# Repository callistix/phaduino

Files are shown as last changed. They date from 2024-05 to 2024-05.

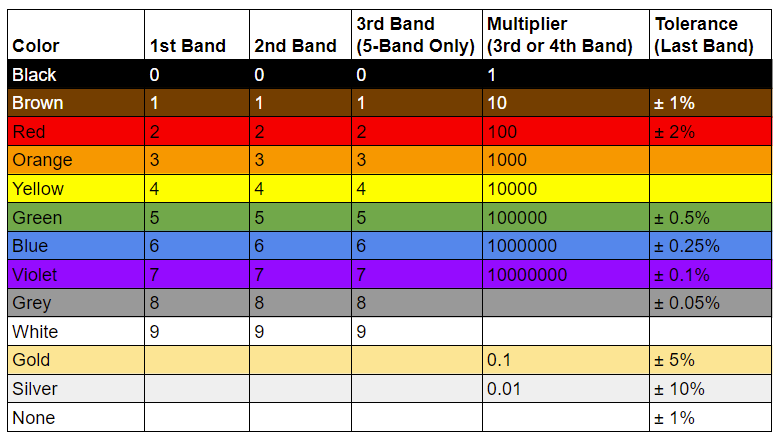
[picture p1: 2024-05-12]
reference/resistor_color_code.png

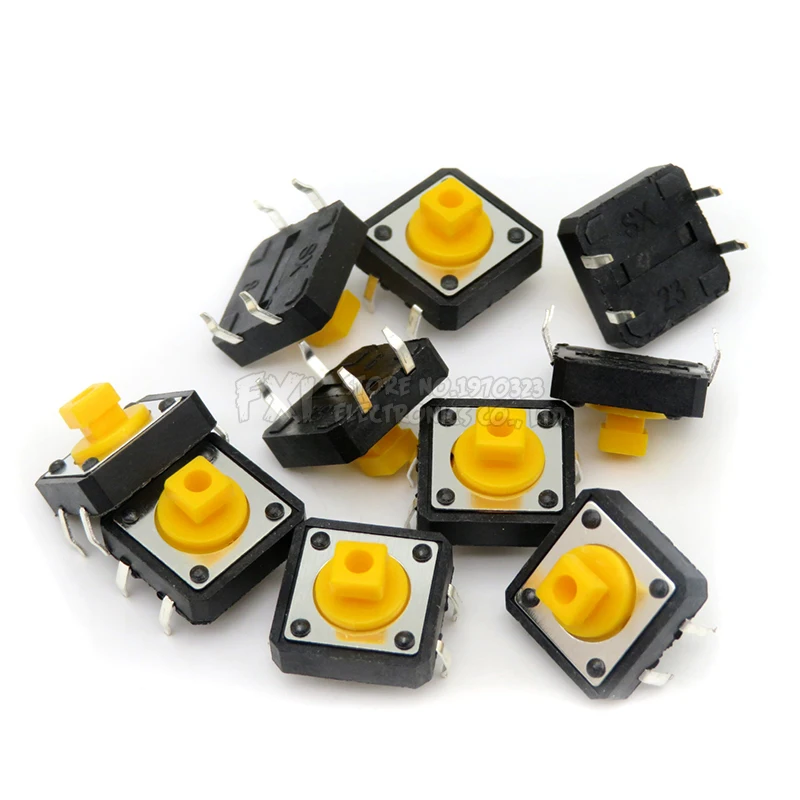
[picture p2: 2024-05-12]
datasheets/Mini Push Button 2.png

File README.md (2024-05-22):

# Requirements

* `apt-get install arduino`
* in Arduino IDE install following libraries:
** MIDI Library
** `CD74HC4067`

# Usage

* flash the original firmware for uploading sketches:

```bash
cd sh
./flash_usbserial
```

* flash the midi firmware to make it appear as MIDI device:

```bash
cd sh
./flash_midi
```

# Print settings

* filament:
    * SUNLU PLA+ black (main)
    * SUNLU PLA+ white (labels)

* nozzle temp.: 220 degrees
* build plate temp.: 75 degrees
* wall line count: 3
* top / bottom layers: 3
* infill: gyroid 20%
* print speed: 50mm/s
* infill speed: 75mm/s
* support speed: 75mm/s
* travel speed: 200mm/s
* retraction distance: 8.0mm
* fan speed: 100%
* support pattern: Zig Zag
* support density: 10%
* use adaptive layers: no

* "Pause at height" setting for filament changing:
    * pause layer: last layer before labels
    * method: BQ
    * keep motors engaged
    * park print: yes
    * retraction: 450mm
    * standby temperature: 220 deg.
    * beep at pause
* enable draft shield: yes (to prime extruder after filament change)

# Notes

* let hot bed cool down entirely before attempting to remove print, or otherwise it will warp

# To-do

* build plate needs leveling, right side seems more faint
* when changing to white filament layers, increase nozzle temperature and retraction distance to i.e. 9 or 10mm
    * for black filament, lower to i.e. 6 or 7 mm retraction distance and 220 degrees
* make pot labels font size 1 pixel bigger for better readability
* test and define the way the pieces attach to each other
    * maybe remove screws 5 and 6 again, then print intermediate connector parts

# Links

## Arduino basics

* [Arduino Push Button Tutorial (step by step)](https://www.youtube.com/watch?v=J_07uwur_MI&t=32s)
* [Arduino LED – Complete Tutorial](https://roboticsbackend.com/arduino-led-complete-tutorial/)

## Arduino MIDI controller

* [Quick Hack! - USB MIDI Controller with Arduino UNO](https://www.youtube.com/watch?v=3haK5QGbi_E)
* [Arduino MIDI Library Documentation](https://fortyseveneffects.github.io/arduino_midi_library/index.html)

## Multiplexing analogue pins

* [How can I connect multiple potentiometers (~20) to my Arduino without having to have 20 analogue pins?](https://electronics.stackexchange.com/questions/659309/how-can-i-connect-multiple-potentiometers-20-to-my-arduino-without-having-to)
* [Arduino CD74HC4067 Analog Multiplexer Library, Code Example](https://deepbluembedded.com/arduino-cd74hc4067-analog-multiplexer-library-code/)
* [Muxing Around With The CD74HC4067 + Arduino](https://adam-meyer.com/arduino/CD74HC4067)

## Multiplexing LEDs

* [Multiplexing 7 Segment Displays With Arduino and Shift Registers](https://www.instructables.com/Multiplexing-7-Segment-displays-with-Arduino-and-S/)
* [Charlieplexing](https://en.wikipedia.org/wiki/Charlieplexing)
* [Multiplexing With Arduino and the 74HC595](https://www.instructables.com/Multiplexing-with-Arduino-and-the-74HC595/)
* [Controlling LEDs with A Multiplexer and Arduino](https://makersportal.com/blog/2019/3/12/controlling-leds-with-multiplexer-and-arduino)

## `TLC5947`

* [TLC5947 and TLC59711 PWM LED Driver Breakouts](https://learn.adafruit.com/tlc5947-tlc59711-pwm-led-driver-breakout/overview)
* [Interfacing TLC5947 PWM Module with Arduino (12-Bit LED Drivers)](https://electropeak.com/learn/interfacing-tlc5947-pwm-module-with-arduino-12-bit-led-drivers/)

## 3D Print labelling

* [Labeling Your Parts with Engraver Filler](https://markforged.com/resources/blog/engraver-filler-labeling)
* [3D Print Inlay Lettering](https://www.youtube.com/watch?v=W2f5lI1R6dg)
* [Finishing 3D prints with nailpolish and acetone](https://www.youtube.com/watch?v=4iX6x2MLhH0)

## FreeCAD

* [Draft ShapeString](https://wiki.freecad.org/Draft_ShapeString)
* [Draft ShapeString tutorial](https://wiki.freecad.org/Draft_ShapeString_tutorial)
* [How to create solids from 2D image?](https://www.xsim.info/articles/FreeCAD/en-US/HowTo/Create-solids-from-2D-image.html)

## Measuring

* [How to Measure Amperage](https://www.wikihow.com/Measure-Amperage)

## C++
* [ArduinoSTL](https://github.com/mike-matera/ArduinoSTL)

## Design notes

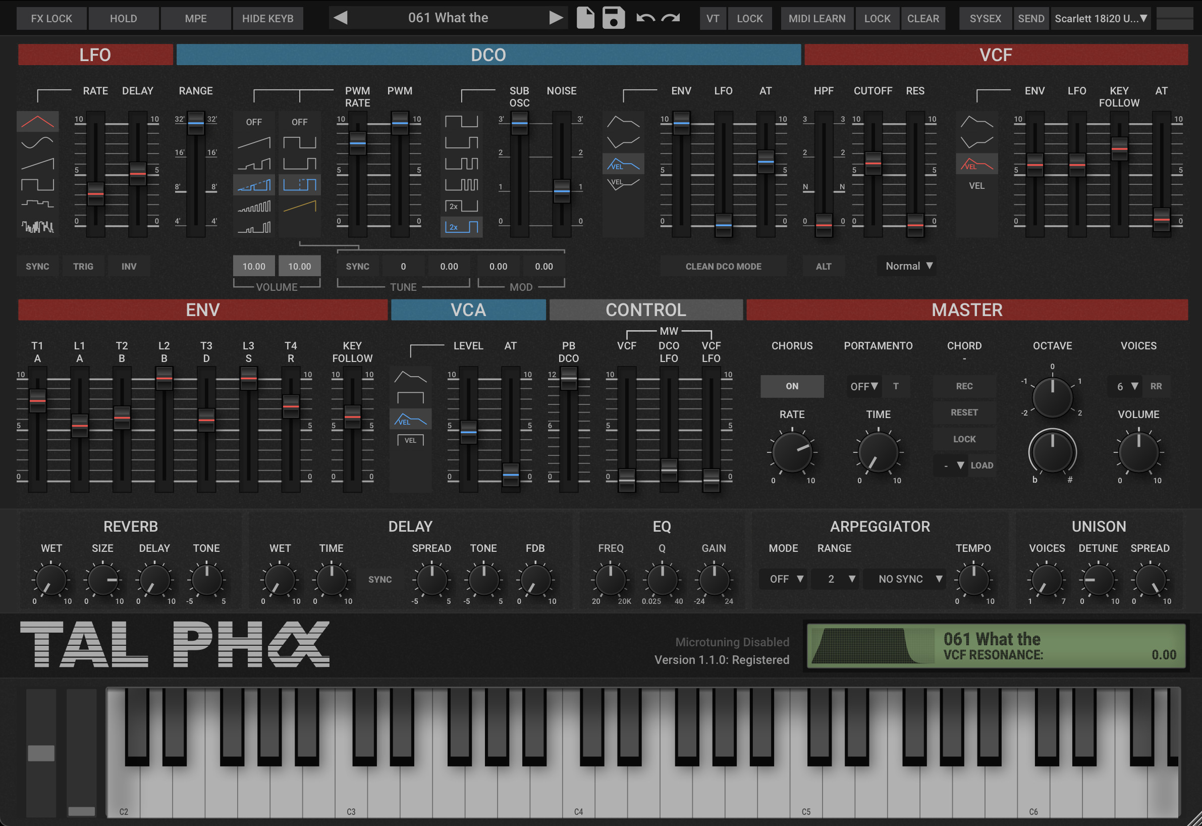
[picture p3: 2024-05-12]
reference/tal-pha.jpg

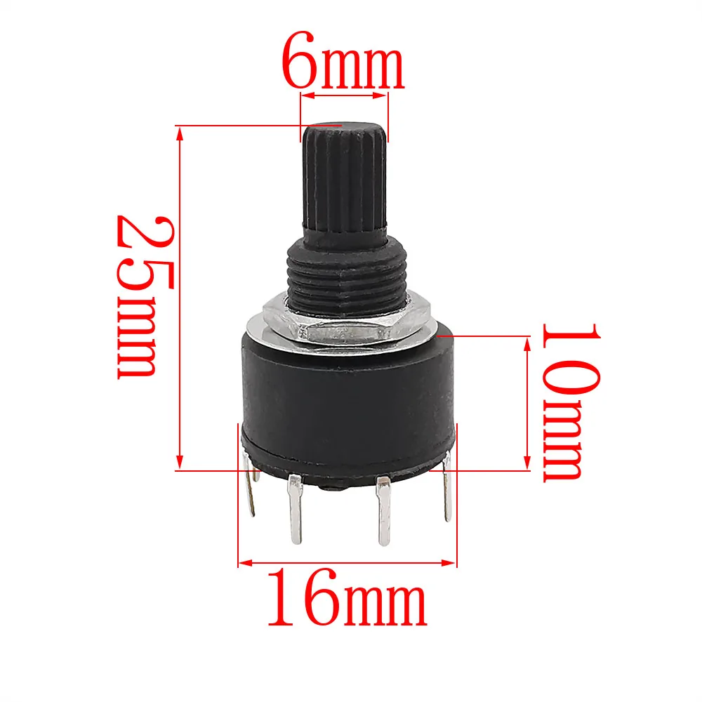
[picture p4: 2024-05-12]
datasheets/SR16 16mm Rotary Band Switch 1 Pole 5 Positions 1.png

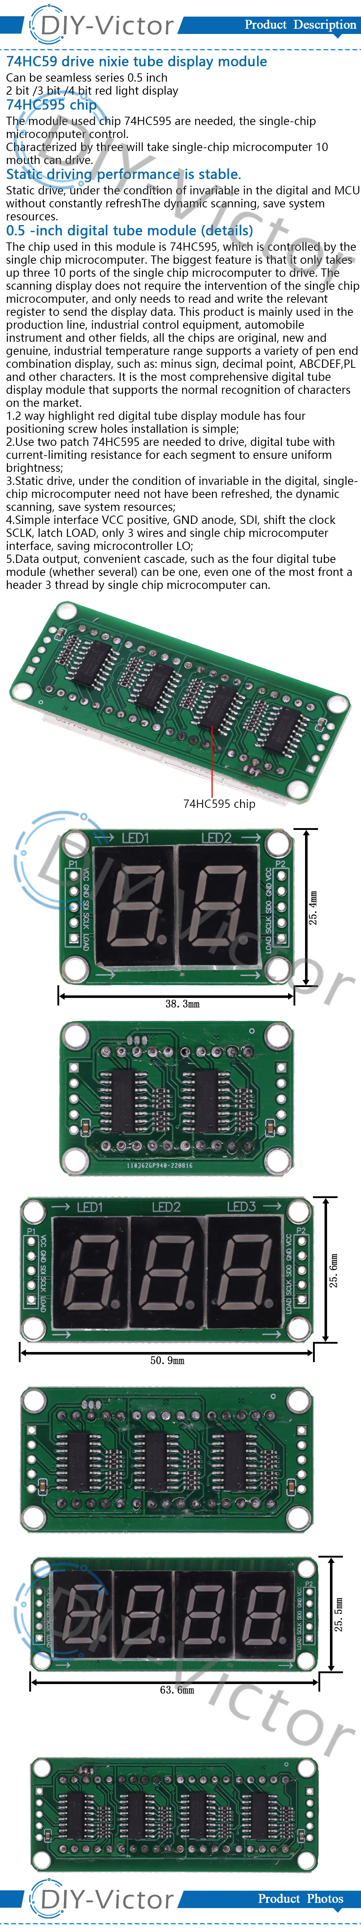
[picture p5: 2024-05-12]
datasheets/5011BS LED 7-Segment Display & SN74HC595.png

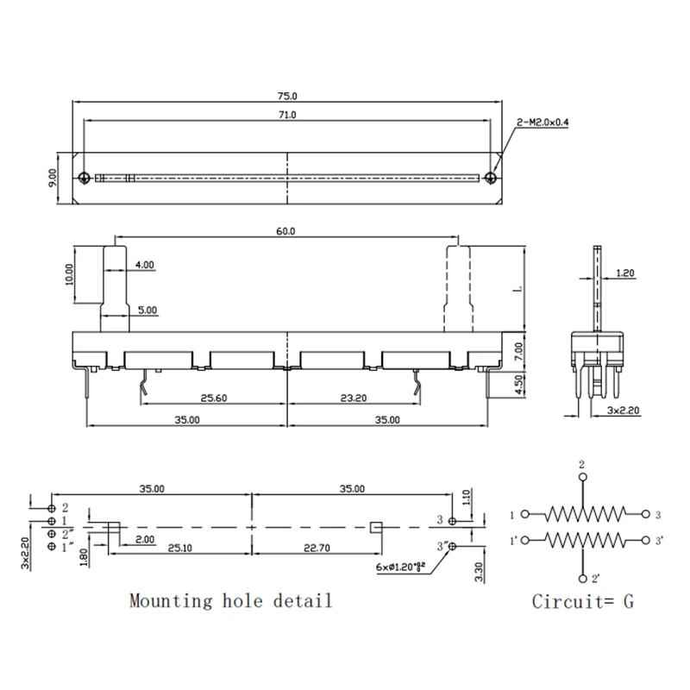
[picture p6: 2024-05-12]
datasheets/SC6080GH 75mm Slide Potentiometer 10k.png

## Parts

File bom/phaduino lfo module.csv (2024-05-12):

Reference | Value | Datasheet | Footprint | Qty | DNP
A1 | Arduino_UNO_R3 | https://www.arduino.cc/en/Main/arduinoBoardUno | Module:Arduino_UNO_R3 | 1
D1/D2/D3 | LED | ~ |  | 3
R1 | 1k | ~ |  | 1
R2 | 560R | ~ |  | 1
R3 | 460R | ~ |  | 1
R4/R7 | 390R | ~ |  | 2
R5/R8 | 180R | ~ |  | 2
R6/R9 | 56R | ~ |  | 2
R10/R11 | 220R | ~ |  | 2
RV1/RV2 | SC6080GH R_Potentiometer | https://ae01.alicdn.com/kf/S4e5feccce45d4e90a10ab3d2473ecfbaM.jpg |  | 2
SW1 | SR16 SW_Rotary_1x6_MP | https://ae01.alicdn.com/kf/S429ed770be804cc08330cb0ba17e1a0cW.jpg |  | 1
SW2/SW3/SW4 | SW_Push | https://ae01.alicdn.com/kf/Ha64b855cd2af4a9e8355bdf6917cb93dQ.jpg |  | 3
U1 | CD74HC4067M | http://www.ti.com/lit/ds/symlink/cd74hc4067.pdf | Package_SO:SOIC-24W_7.5x15.4mm_P1.27mm | 1
U2 | TLC5947DAP | https://www.ti.com/lit/ds/symlink/tlc5947.pdf | Package_SO:HTSSOP-32-1EP_6.1x11mm_P0.65mm_EP5.2x11mm_Mask4.11x4.36mm_ThermalVias | 1

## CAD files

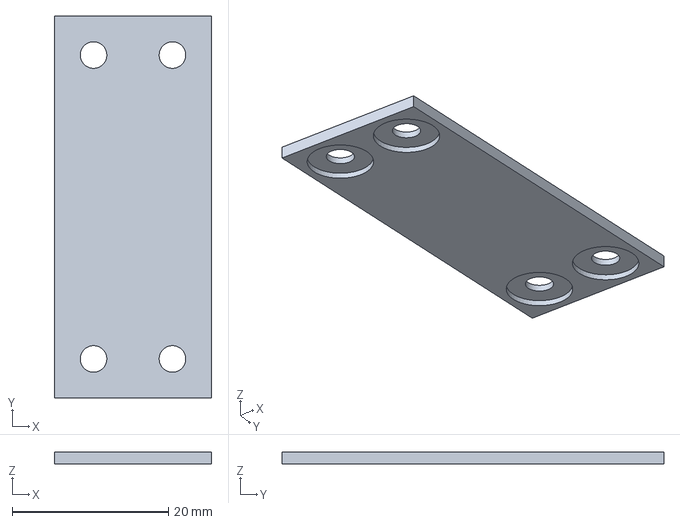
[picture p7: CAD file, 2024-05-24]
freecad/frame.FCStd
20.1 x 48.9 x 1.50 mm

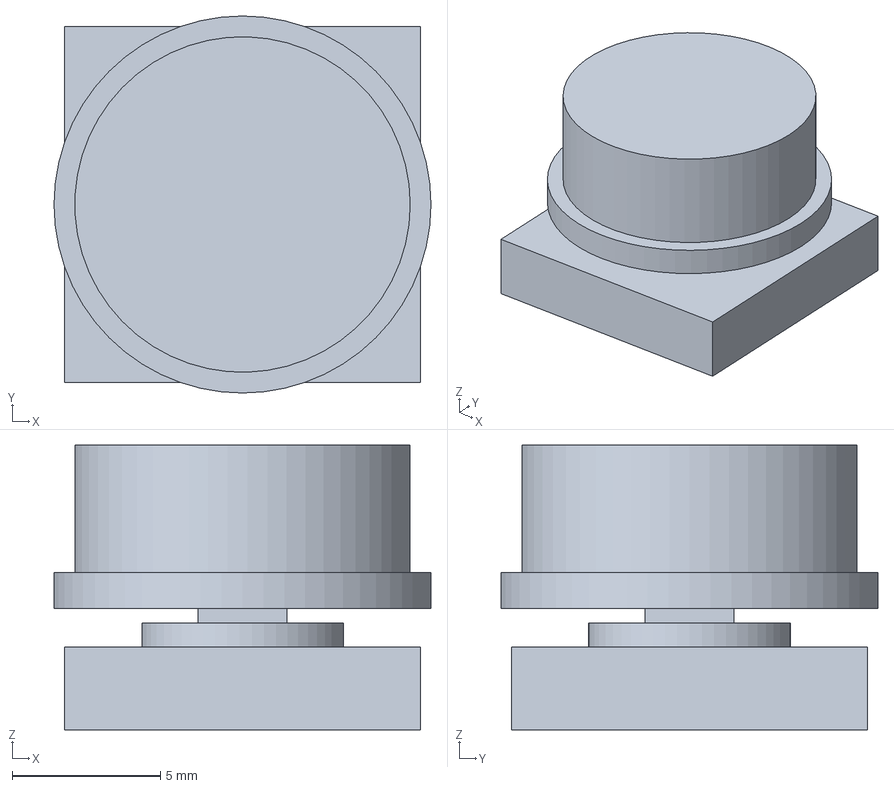
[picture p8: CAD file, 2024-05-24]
freecad/parts/mini_push_button.FCStd
12.7 x 12.7 x 9.60 mm

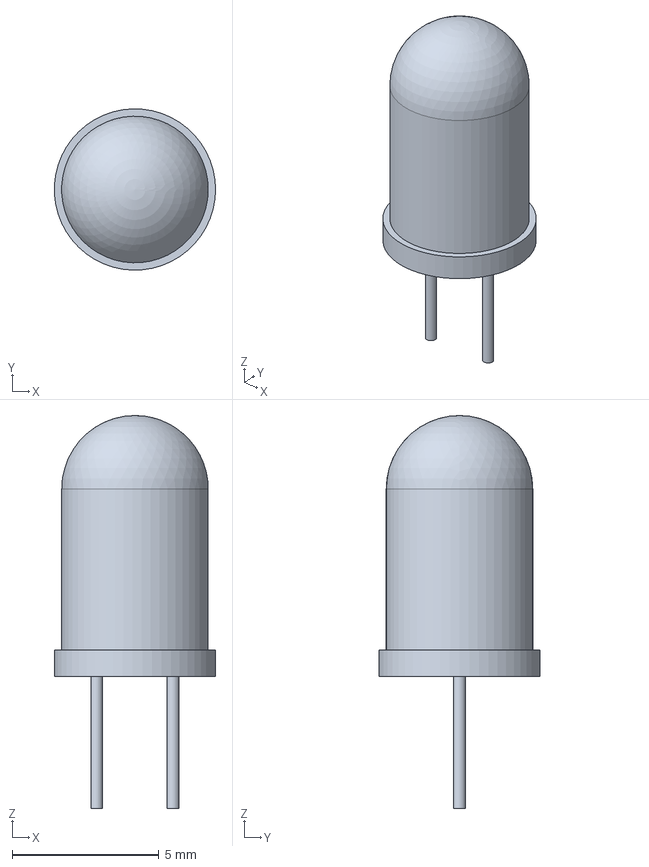
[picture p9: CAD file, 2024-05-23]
freecad/parts/led.FCStd
5.49 x 5.50 x 13.4 mm

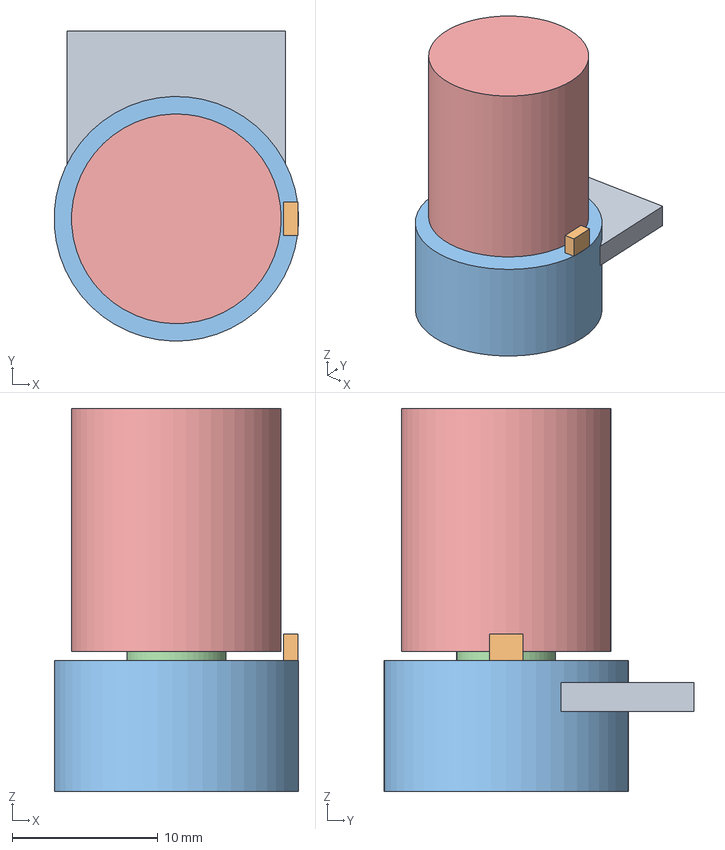
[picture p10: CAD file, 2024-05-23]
freecad/parts/pot_r.FCStd
16.8 x 21.3 x 26.3 mm
pot_connectors
pot_notch
pot_body
pot_shaft
pot_knob
pot_washer

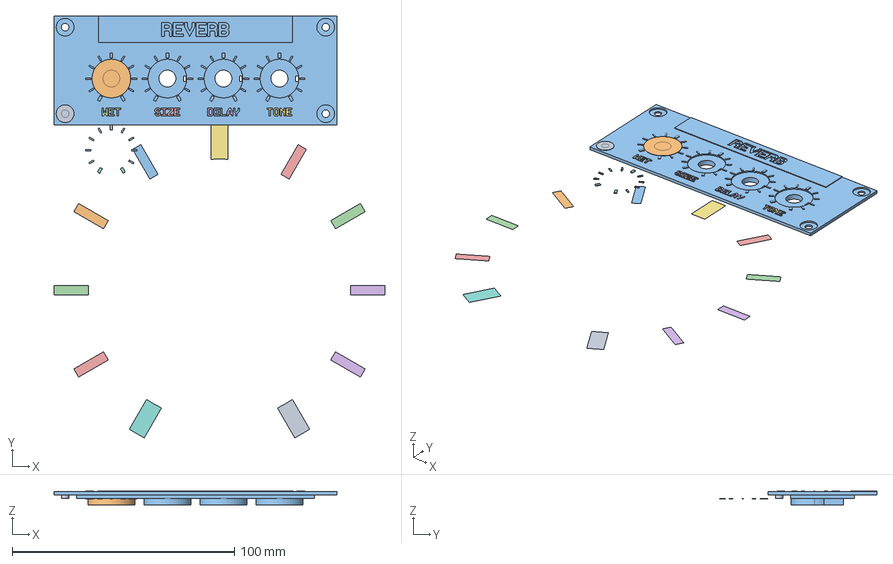
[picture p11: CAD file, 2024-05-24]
freecad/reverb.FCStd
148.8 x 189.7 x 6.32 mm
panel_slit_1
pot_cage_1
title
label_1
label_2
label_3
label_4
label_dial_1
panel_screw_1
panel_pot_cut_1
panel
rect2637
rect2637_008
rect2637_009
rect2637_3
rect2637_3_2
rect2637_3_6
rect2637_6
rect2637_6_5
rect2637_7
rect2637_7_5
rect2638

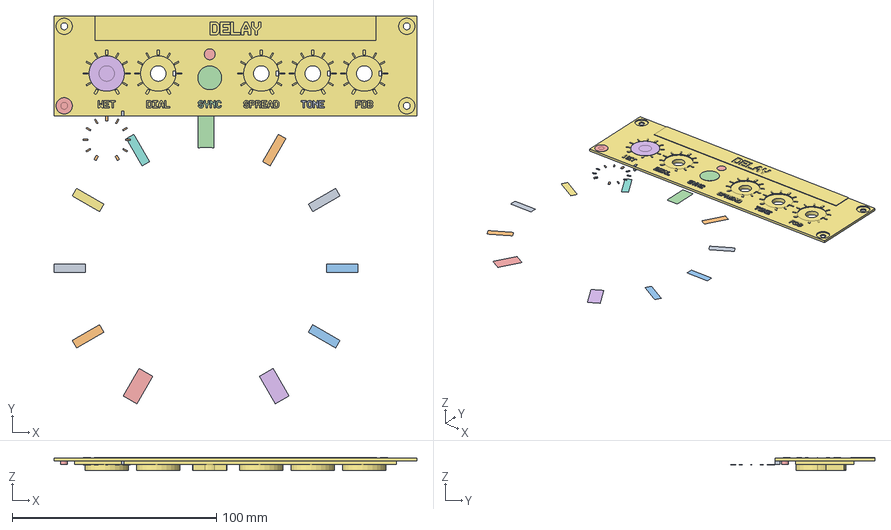
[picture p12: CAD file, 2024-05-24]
freecad/delay.FCStd
177.6 x 189.7 x 6.32 mm
panel_slit_1
pot_cage_1
title
push_cut
led_cut
label_1
label_2
label_4
label_5
label_dial_1
label_6
label_3
panel_screw_1
panel_pot_cut_1
panel
push_led_cage
rect2637
rect2637_008
rect2637_009
rect2637_3
rect2637_3_2
rect2637_3_6
rect2637_6
rect2637_6_5
rect2637_7
rect2637_7_5
rect2638

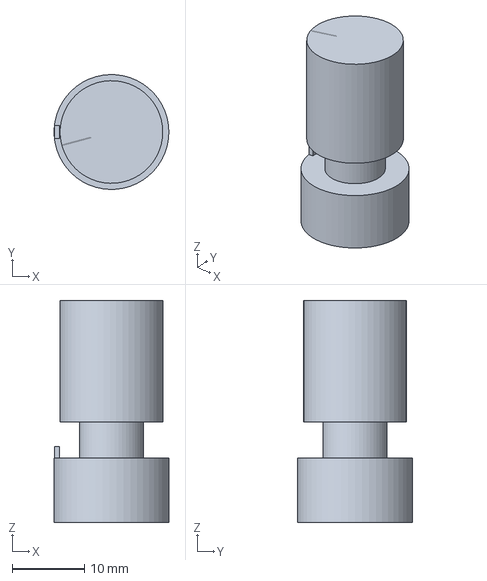
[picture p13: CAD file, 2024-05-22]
freecad/parts/switch_rot.FCStd
15.9 x 15.9 x 30.7 mm

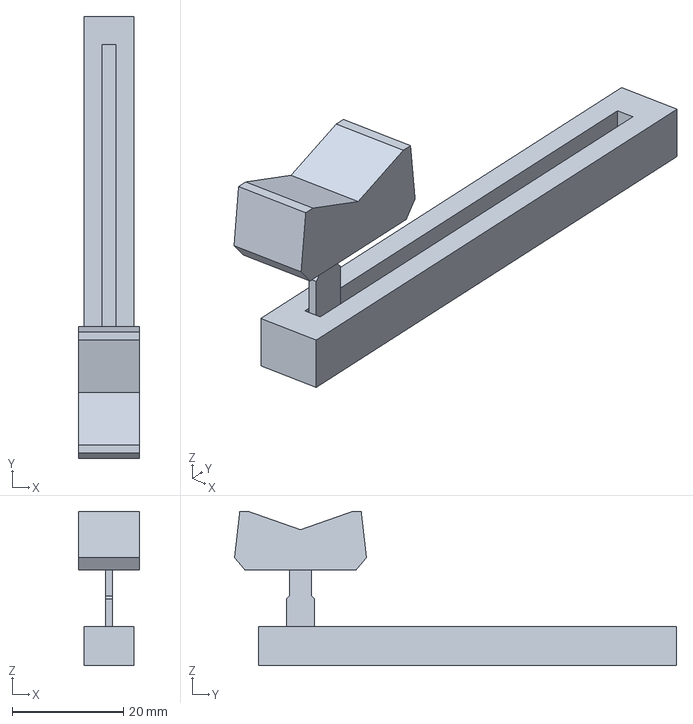
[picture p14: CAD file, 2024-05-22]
freecad/parts/pot_slide.FCStd
10.9 x 79.3 x 27.7 mm

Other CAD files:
freecad/main.FCStd
freecad/parts/pot.FCStd

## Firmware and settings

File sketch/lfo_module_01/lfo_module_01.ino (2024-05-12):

/* TODO:
   * midi_cc are still unstable for potentiometers at certain positions
   * needs optimisation especially for reading LFO buttons
*/

#include "Adafruit_TLC5947.h"


#define BAUD 9600
#define DELAY 1
#define POT_AVG 3
#define MUX_COUNT 1
#define RES_TOLERANCE 5
#define SWITCH_TOLERANCE 10

#define TLC_NUM 1
#define TLC_DATA 6
#define TLC_CLOCK 7
#define TLC_LATCH 8
#define TLC_OE -1


const int mux_signal_pin = A0;

const int mux[MUX_COUNT][4] = {
	{2, 3, 4, 5},
};

const int mux_channel[16][4]={
	{0,0,0,0},
	{1,0,0,0},
	{0,1,0,0},
	{1,1,0,0},
	{0,0,1,0},
	{1,0,1,0},
	{0,1,1,0},
	{1,1,1,0},
	{0,0,0,1},
	{1,0,0,1},
	{0,1,0,1},
	{1,1,0,1},
	{0,0,1,1},
	{1,0,1,1},
	{0,1,1,1},
	{1,1,1,1}
};

const int btn_lfo_sync_res = 369;
const int btn_lfo_trig_res = 562;
const int btn_lfo_sync_trig_res = 654;
const int btn_lfo_inv_res = 811;
const int btn_lfo_sync_inv_res = 832;
const int btn_lfo_trig_inv_res = 865;

const int switch_6_pos_res[] = {802, 557, 365, 325, 286, 182};

typedef struct {
	int val[POT_AVG];
    int val_ptr = 0;
    int midi_cc = 0;
} potentiometer_t;


typedef struct {
    bool sync = false;
    bool sync_hold = false;
    bool trig = false;
    bool trig_hold = false;
    bool inv = false;
    bool inv_hold = false;
} buttons_lfo_t;

typedef struct {
    int midi_cc = 0;
} switch_6_pos_t;


Adafruit_TLC5947 tlc = Adafruit_TLC5947(TLC_NUM, TLC_CLOCK, TLC_DATA, TLC_LATCH);

potentiometer_t pot_lfo_rate;
potentiometer_t pot_lfo_delay;

buttons_lfo_t buttons_lfo;

switch_6_pos_t switch_lfo_wave;


void setup() {
    Serial.begin(BAUD);

    tlc.begin();

    tlc.setLED(0,4059,0,0);
    tlc.write();

	pot_init(pot_lfo_rate);
	pot_init(pot_lfo_delay);

    for (int i = 0; i < MUX_COUNT; i++) {
        mux_init_pins(mux[i]);
	    mux_switch_channel(mux[0], 0);
    }
}


void loop() {
    int midi_cc = 0;

    midi_cc = mux_read_pot(0, 0, pot_lfo_rate);

    if (midi_cc != pot_lfo_rate.midi_cc) {
        pot_lfo_rate.midi_cc = midi_cc;

        Serial.print("LFO RATE: ");
        Serial.println(pot_lfo_rate.midi_cc);
    }

    midi_cc = mux_read_pot(0, 1, pot_lfo_delay);

    if (midi_cc != pot_lfo_delay.midi_cc) {
        pot_lfo_delay.midi_cc = midi_cc;

        Serial.print("LFO DELAY: ");
        Serial.println(pot_lfo_delay.midi_cc);
    }

    mux_read_buttons_lfo(0, 2, buttons_lfo);

    midi_cc = mux_read_6_pos_switch(0, 3, switch_lfo_wave);

    if ((midi_cc != -1) && (midi_cc != switch_lfo_wave.midi_cc)) {
        switch_lfo_wave.midi_cc = midi_cc;

        Serial.print("LFO WAVE: ");
        Serial.println(switch_lfo_wave.midi_cc);
    }

    delay(DELAY);
}


int mux_read_pot(int mux_no, int channel, potentiometer_t &pot) {
    int midi_cc = 0;

    mux_switch_channel(mux_no, channel);

    pot.val[pot.val_ptr] = analogRead(A0);

    pot.val_ptr++;
    if (pot.val_ptr >= POT_AVG) pot.val_ptr = 0;

    midi_cc = val2midi_cc(avg(pot.val, POT_AVG));

    return(midi_cc);
}


void mux_read_buttons_lfo(int mux_no, int channel, buttons_lfo_t &btns) {
    mux_switch_channel(mux_no, channel);

    int btns_val = analogRead(A0);

//    Serial.println(btns_val);

    if ((btns_val > btn_lfo_sync_res - RES_TOLERANCE) && (btns_val < btn_lfo_sync_res + RES_TOLERANCE)) {
        if (btns.sync_hold == false) {
            Serial.print("LFO SYNC: ");
            button_toggle(btns.sync, btns.sync_hold);
        }

        btns.trig_hold = false;
        btns.inv_hold = false;
    } else if ((btns_val > btn_lfo_trig_res - RES_TOLERANCE) && (btns_val < btn_lfo_trig_res + RES_TOLERANCE)) {
        if (btns.trig_hold == false) {
            Serial.print("LFO TRIG: ");
            button_toggle(btns.trig, btns.trig_hold);
        }

        btns.sync_hold = false;
        btns.inv_hold = false;
    } else if ((btns_val > btn_lfo_sync_trig_res - RES_TOLERANCE) && (btns_val < btn_lfo_sync_trig_res + RES_TOLERANCE)) {
        if (btns.sync_hold == false) {
            Serial.print("LFO SYNC: ");
            button_toggle(btns.sync, btns.sync_hold);
        }

        if (btns.trig_hold == false) {
            Serial.print("LFO TRIG: ");
            button_toggle(btns.trig, btns.trig_hold);
        }

        btns.inv_hold = false;
    } else if ((btns_val > btn_lfo_inv_res - RES_TOLERANCE) && (btns_val < btn_lfo_inv_res + RES_TOLERANCE)) {
        if (btns.inv_hold == false) {
            Serial.print("LFO INV: ");
            button_toggle(btns.inv, btns.inv_hold);
        }

        btns.trig_hold = false;
        btns.sync_hold = false;
    } else if ((btns_val > btn_lfo_sync_inv_res - RES_TOLERANCE) && (btns_val < btn_lfo_sync_inv_res + RES_TOLERANCE)) {
        if (btns.sync_hold == false) {
            Serial.print("LFO SYNC: ");
            button_toggle(btns.sync, btns.sync_hold);
        }

        if (btns.inv_hold == false) {
            Serial.print("LFO INV: ");
            button_toggle(btns.inv, btns.inv_hold);
        }

        btns.trig_hold = false;
    } else if ((btns_val > btn_lfo_trig_inv_res - RES_TOLERANCE) && (btns_val < btn_lfo_trig_inv_res + RES_TOLERANCE)) {
        if (btns.trig_hold == false) {
            Serial.print("LFO TRIG: ");
            button_toggle(btns.trig, btns.trig_hold);
        }

        if (btns.inv_hold == false) {
            Serial.print("LFO INV: ");
            button_toggle(btns.inv, btns.inv_hold);
        }

        btns.sync_hold = false;
    } else if (btns_val < RES_TOLERANCE) {
        btns.sync_hold = false;
        btns.trig_hold = false;
        btns.inv_hold = false;
    }
}


int mux_read_6_pos_switch(int mux_no, int channel, switch_6_pos_t &swch) {
    int midi_cc = 0;

    mux_switch_channel(mux_no, channel);

    int swch_val = analogRead(A0);

    if ((swch_val > switch_6_pos_res[0] - SWITCH_TOLERANCE) && (swch_val < switch_6_pos_res[0] + SWITCH_TOLERANCE)) midi_cc = 0;
    else if ((swch_val > switch_6_pos_res[1] - SWITCH_TOLERANCE) && (swch_val < switch_6_pos_res[1] + SWITCH_TOLERANCE)) midi_cc = 25;
    else if ((swch_val > switch_6_pos_res[2] - SWITCH_TOLERANCE) && (swch_val < switch_6_pos_res[2] + SWITCH_TOLERANCE)) midi_cc = 51;
    else if ((swch_val > switch_6_pos_res[3] - SWITCH_TOLERANCE) && (swch_val < switch_6_pos_res[3] + SWITCH_TOLERANCE)) midi_cc = 76;
    else if ((swch_val > switch_6_pos_res[4] - SWITCH_TOLERANCE) && (swch_val < switch_6_pos_res[4] + SWITCH_TOLERANCE)) midi_cc = 102;
    else if ((swch_val > switch_6_pos_res[5] - SWITCH_TOLERANCE) && (swch_val < switch_6_pos_res[5] + SWITCH_TOLERANCE)) midi_cc = 127;
    else midi_cc = -1;

    return(midi_cc);
}


void button_toggle(bool &button, bool &hold) {
    hold = true;

    if (button == true) {
        button = false;

        tlc.setLED(0, 0, 0, 0);
        tlc.write();
    } else {
        button = true;

        tlc.setLED(0, 4059, 0, 0);
        tlc.write();
    }

    Serial.println(button);
}


void mux_switch_channel(int mux_no, int channel) {
	for (int i = 0; i < 4; i++) {
        digitalWrite(mux[mux_no][i], mux_channel[channel][i]);
	}
}


void pot_init(potentiometer_t &pot) {
    for (int i = 0; i < POT_AVG; i++) {
        pot.val[i] = 0;
    }
}


int avg(int *arr, int arr_size) {
    int val_avg = 0;

    for (int i = 0; i < arr_size; i++) {
        val_avg = val_avg + arr[i];
    }

    val_avg = val_avg / POT_AVG;

    return(val_avg);
}


int val2midi_cc(int val) {
    int midi_cc = 0;

    midi_cc = int(val / 8.0551);

    return (midi_cc);
}


int mux_init_pins(int *mux) {
    for (int pin = 0; pin < 3; pin++) {
        pinMode(mux[pin], OUTPUT);
    }
}

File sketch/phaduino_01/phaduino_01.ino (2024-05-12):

#include <MIDI.h>

MIDI_CREATE_DEFAULT_INSTANCE();

int const potpins[] = {A0, A1, A2, A3, A4};
int const cc_offset = 16;
int const smoothing = 2;

int potval[] = {0, 0, 0, 0, 0};
int potval_old[] = {0, 0, 0, 0, 0};


void setup() {
  MIDI.begin(MIDI_CHANNEL_OMNI);
}


void loop() {
    int midi_cc_val;

    for (int pin = 0; pin < 5; pin++) {
        potval[pin] = analogRead(potpins[pin]);

        if (potval[pin] > potval_old[pin] + smoothing or potval[pin] < potval_old[pin] - smoothing) {
            potval_old[pin] = potval[pin];

            /* potval[] ranges from 0 to 1023, map to MIDI CC range 0 to 127 */
            midi_cc_val = potval[pin] / 8.0551;

            MIDI.sendControlChange(cc_offset + pin, midi_cc_val, 1);
        }
    }
}

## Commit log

2024-05-13 improve freecad model
    [phaduino.FCStd]
2024-05-13 redo freecad sketch with links rather than copies of objects
    [test.FCStd]
2024-05-19 restart freecad sketch to account for reverse pots
    [phaduino 2.FCStd, phaduino 3.FCStd, pot_reverse.FCStd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]
2024-05-20 finish first full test of lfo module print
    [phaduino 3.FCStd, phaduino 4.FCStd]
2024-05-22 modular version of freecad sketch
    [delay_old.FCStd, led.FCStd, lfo.FCStd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]
2024-05-22 add delay freecad sketch
    [delay.FCStd, delay_old.FCStd, main.FCStd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]
2024-05-23 finish delay module in freecad
    [delay.FCStd, led.FCStd, main.FCStd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]
2024-05-24 small changes to freecad model
    [delay.FCStd, frame.FCStd, main.FCStd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]
